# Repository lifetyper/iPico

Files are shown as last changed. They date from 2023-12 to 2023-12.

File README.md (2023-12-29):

# iPico
Open Hardware Secure Key Using Pico Fido Firmware

iPico PCB and Enclosure.

1.Using same gpio as raspi pico

2.Light guide using Φ2*2.54mm

3.Screw using M1*4mm

4.Keep USB footprint bottom side clean without too much solder

5.You might need to polish the outline of PCB if it's not done by the manufacture

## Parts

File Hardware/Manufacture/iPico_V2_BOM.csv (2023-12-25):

# | Reference | Qty | Value | Footprint | DNP
1 | C1, C2, C5, C6, C9, C10, C19 | 7 | C_0402_2.2uF_10V_X5R | Capacitor_SMD:C_0402_1005Metric
2 | C3 | 1 | C_0402_1uF_10V_X7R | Capacitor_SMD:C_0402_1005Metric
3 | C4, C8, C11, C12, C14, C15, C18 | 7 | C_0402_100nF_16V_X7R | Capacitor_SMD:C_0402_1005Metric
4 | C7, C17 | 2 | C_0402_22nF_50V_X7R | Capacitor_SMD:C_0402_1005Metric
5 | C13, C16 | 2 | C_0402_15pF_50V_C0G | Capacitor_SMD:C_0402_1005Metric
6 | D1, D2 | 2 | PESD0402-140 | Diode_SMD:D_0402_1005Metric
7 | D3 | 1 | NCD0603G1 | LED_SMD:LED_0603_1608Metric
8 | F1 | 1 | BSMD0603-020-16V | Fuse:Fuse_0603_1608Metric
9 | H1, H2, H3 | 3 | MountingHole_Pad | TinyMountingHole:MountingHole-M1
10 | J1 | 1 | GT-USB-8016A | GT-USB-8016A:GT-USB-8016A
11 | R1 | 1 | R_0402_5.1K_5% | Resistor_SMD:R_0402_1005Metric
12 | R2, R3 | 2 | R_0402_27_5% | Resistor_SMD:R_0402_1005Metric
13 | R4 | 1 | R_0402_200_5% | Resistor_SMD:R_0402_1005Metric
14 | R5, R6 | 2 | R_0402_1K_5% | Resistor_SMD:R_0402_1005Metric
15 | R7 | 1 | R_0402_470_5% | Resistor_SMD:R_0402_1005Metric
16 | SW1 | 1 | TS-1187A-C-H-B | SW_PUSH_1P1P_XKB_TS-1187A_W3D:SW_Push_1P1T_XKB_TS-1187A
17 | U1 | 1 | W25Q16JVUXIQ | USON8:USON8-2x3mm-EP0.2x1.6mm
18 | U2 | 1 | RT9013-33GB | Package_TO_SOT_SMD:SOT-23-5
19 | U4 | 1 | RP2040 | Package_DFN_QFN:QFN-56-1EP_7x7mm_P0.4mm_EP3.2x3.2mm
20 | Y1 | 1 | X322512MMB4SI | Crystal:Crystal_SMD_2520-4Pin_2.5x2.0mm

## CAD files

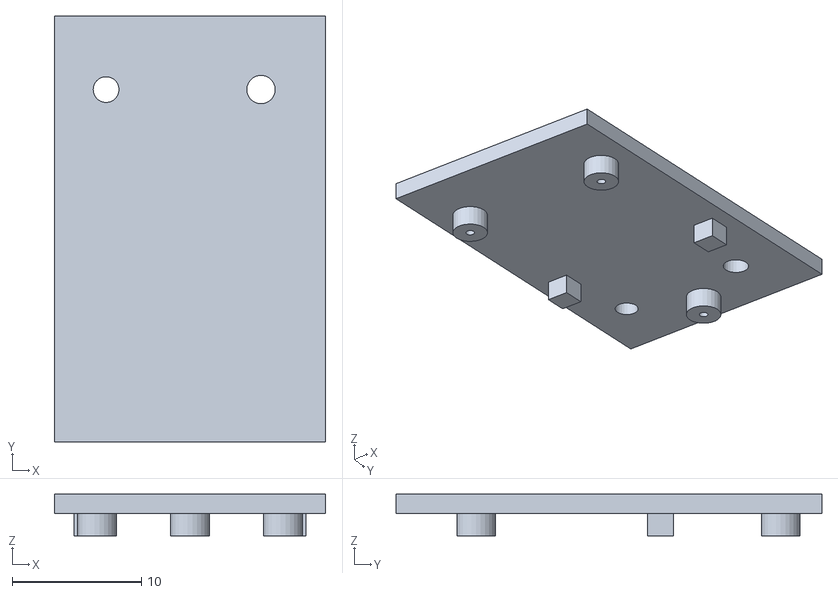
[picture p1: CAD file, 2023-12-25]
Mechanical/Enclosure/iPico_V2-Upper.stl
21.0 x 33.0 x 3.25

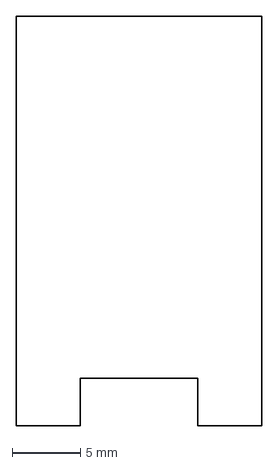
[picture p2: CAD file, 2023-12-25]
Mechanical/PCB_Outline/pcb_outline-Sketch.dxf
18.0 x 30.0 mm

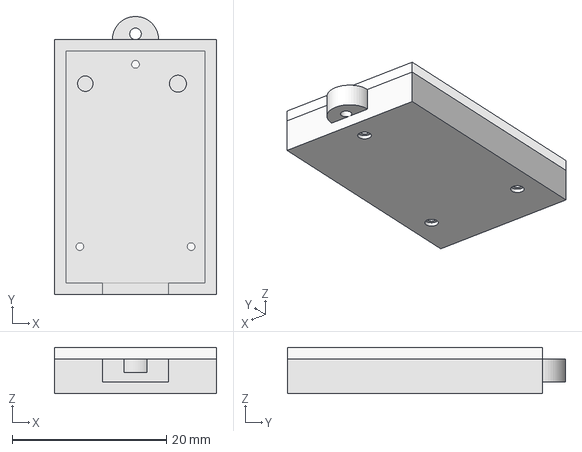
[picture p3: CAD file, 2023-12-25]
Mechanical/Enclosure/iPico_V2.FCStd
21.0 x 36.0 x 6.00 mm
Lower
Upper

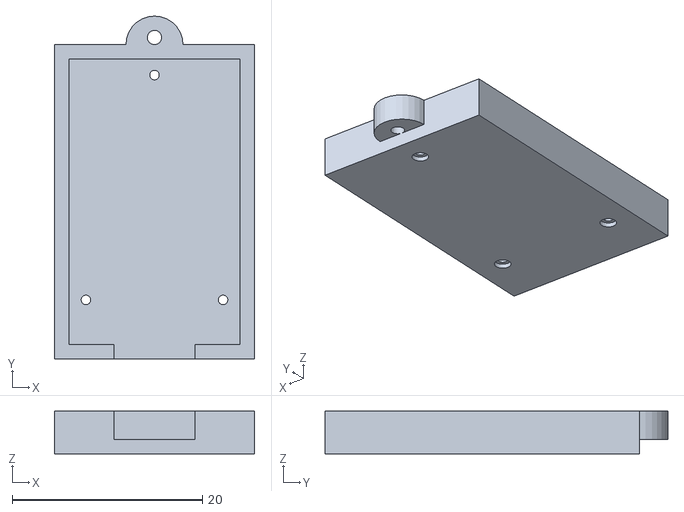
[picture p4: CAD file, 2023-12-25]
Mechanical/Enclosure/iPico_V2-Lower.stl
21.0 x 36.0 x 4.50

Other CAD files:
Mechanical/PCB_Outline/pcb_outline.FCStd

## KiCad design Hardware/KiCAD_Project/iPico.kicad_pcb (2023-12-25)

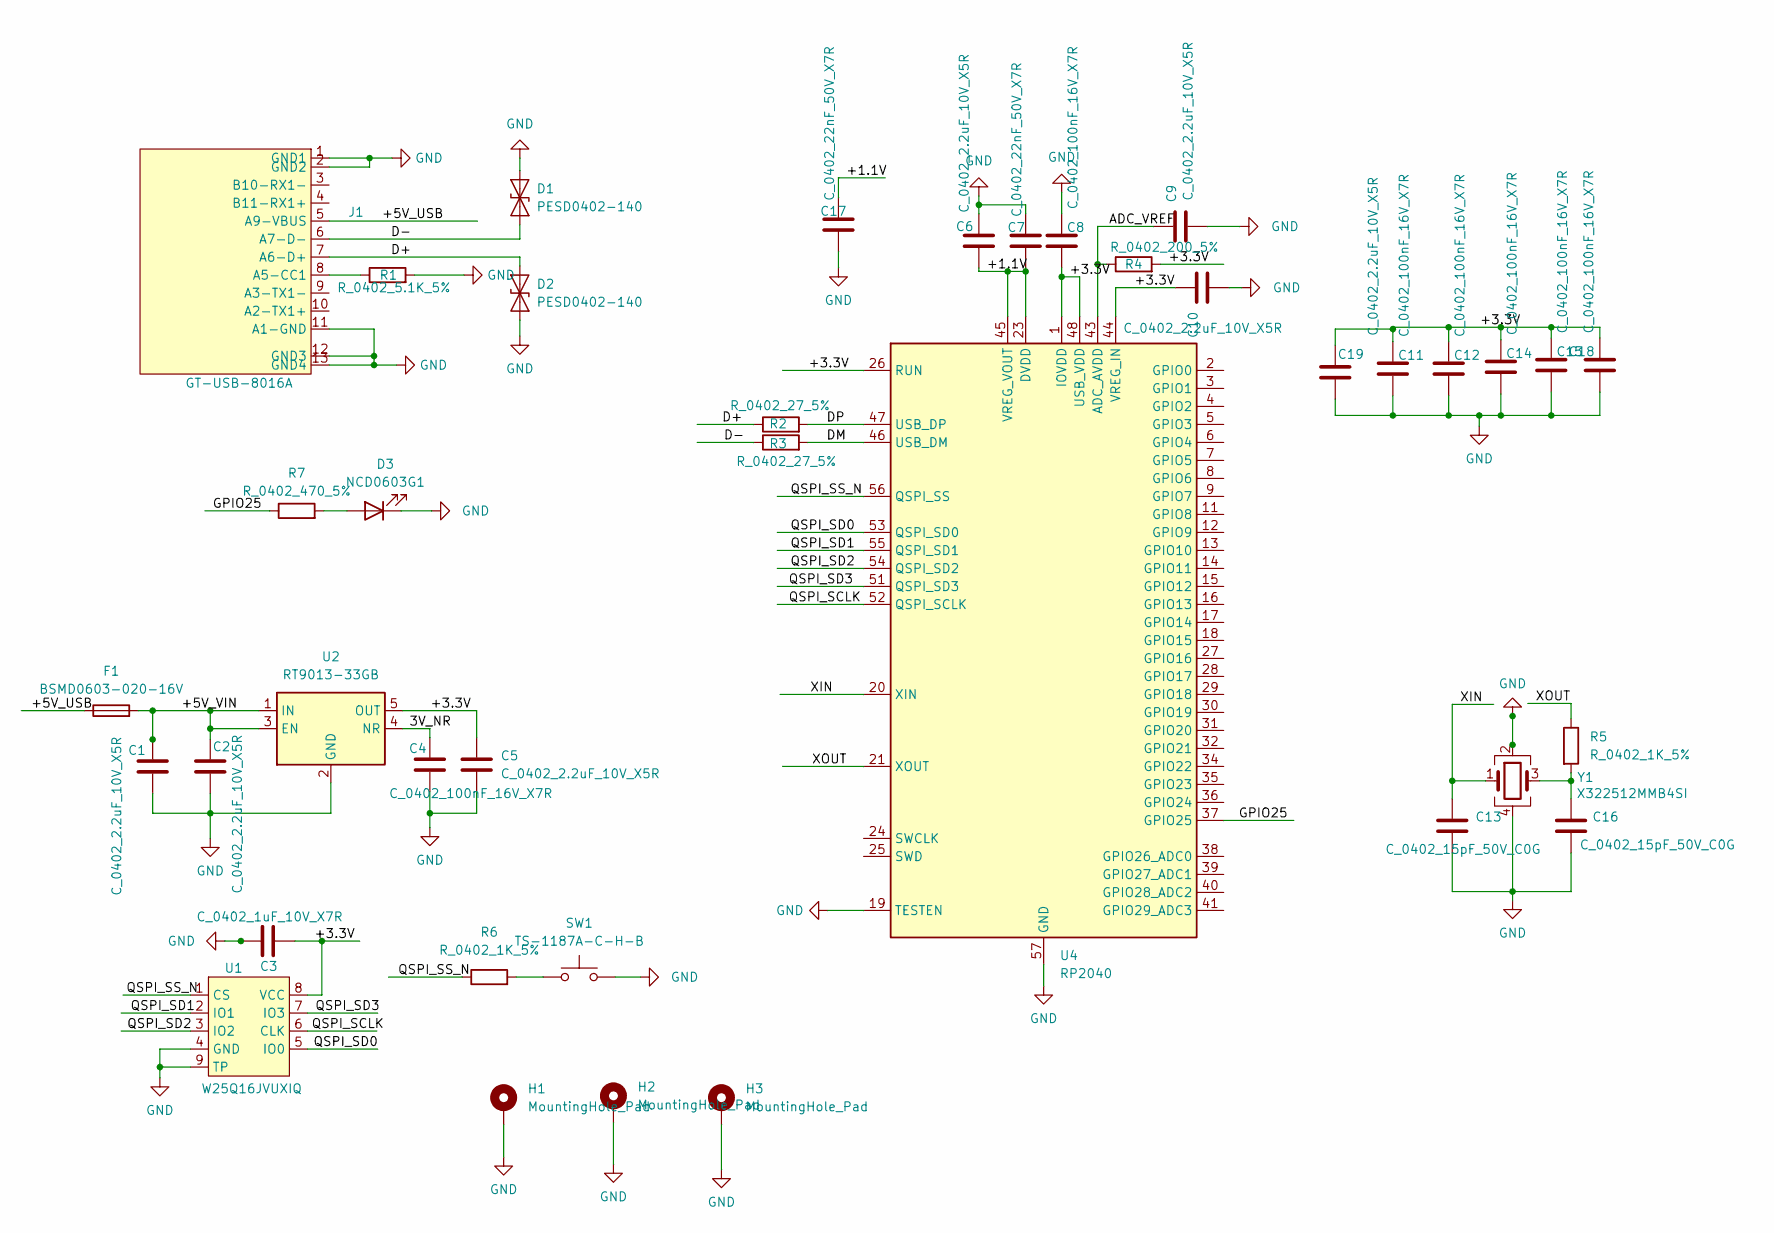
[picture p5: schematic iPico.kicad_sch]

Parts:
C1, C2, C5, C6, C9, C10, C19: C_0402_2.2uF_10V_X5R; C_0402_1005Metric
C3: C_0402_1uF_10V_X7R; C_0402_1005Metric
C4, C8, C11, C12, C14, C15, C18: C_0402_100nF_16V_X7R; C_0402_1005Metric
C7, C17: C_0402_22nF_50V_X7R; C_0402_1005Metric
C13, C16: C_0402_15pF_50V_C0G; C_0402_1005Metric
D1, D2: PESD0402-140; D_0402_1005Metric
D3: NCD0603G1; LED_0603_1608Metric
F1: BSMD0603-020-16V; Fuse_0603_1608Metric
H1, H2, H3: MountingHole_Pad; MountingHole-M1
J1: GT-USB-8016A
R1: R_0402_5.1K_5%; R_0402_1005Metric
R2, R3: R_0402_27_5%; R_0402_1005Metric
R4: R_0402_200_5%; R_0402_1005Metric
R5, R6: R_0402_1K_5%; R_0402_1005Metric
R7: R_0402_470_5%; R_0402_1005Metric
SW1: TS-1187A-C-H-B; SW_Push_1P1T_XKB_TS-1187A
U1: W25Q16JVUXIQ; USON8-2x3mm-EP0.2x1.6mm
U2: RT9013-33GB; SOT-23-5
U4: RP2040; QFN-56-1EP_7x7mm_P0.4mm_EP3.2x3.2mm
Y1: X322512MMB4SI; Crystal_SMD_2520-4Pin_2.5x2.0mm

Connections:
/3V_NR: C4.1, U2.4 (NR)
/+1.1V: C6.2, C7.2, C17.1, U4.23 (DVDD), U4.45 (VREG_VOUT), U4.50 (DVDD)
/+3.3V: C3.2, C5.1, C8.2, C10.1, C11.1, C12.1, C14.1, C15.1, C18.1, C19.2, R4.2, U1.8 (VCC), U2.5 (OUT), U4.1 (IOVDD), U4.10 (IOVDD), U4.22 (IOVDD), U4.26 (RUN), U4.33 (IOVDD), U4.42 (IOVDD), U4.44 (VREG_IN), U4.48 (USB_VDD), U4.49 (IOVDD)
/+5V_USB: F1.1, J1.5 (A9-VBUS)
/+5V_VIN: C1.1, C2.1, F1.2, U2.1 (IN), U2.3 (EN)
/ADC_VREF: C9.1, R4.1, U4.43 (ADC_AVDD)
/D+: D2.2 (A2), J1.7 (A6-D+), R2.1
/D-: D1.1 (A1), J1.6 (A7-D-), R3.1
/DM: R3.2, U4.46 (USB_DM)
/DP: R2.2, U4.47 (USB_DP)
/GPIO25: R7.1, U4.37 (GPIO25)
/QSPI_SCLK: U1.6 (CLK), U4.52 (QSPI_SCLK)
/QSPI_SD0: U1.5 (IO0), U4.53 (QSPI_SD0)
/QSPI_SD1: U1.2 (IO1), U4.55 (QSPI_SD1)
/QSPI_SD2: U1.3 (IO2), U4.54 (QSPI_SD2)
/QSPI_SD3: U1.7 (IO3), U4.51 (QSPI_SD3)
/QSPI_SS_N: R6.1, U1.1 (CS), U4.56 (QSPI_SS)
/XIN: C13.1, U4.20 (XIN), Y1.1
/XOUT: R5.1, U4.21 (XOUT)
GND: C1.2, C2.2, C3.1, C4.2, C5.2, C6.1, C7.1, C8.1, C9.2, C10.2, C11.2, C12.2, C13.2, C14.2, C15.2, C16.2, C17.2, C18.2, C19.1, D1.2 (A2), D2.1 (A1), D3.1 (K), H1.1, H2.1, H3.1, J1.1 (GND1), J1.2 (GND2), J1.11 (A1-GND), J1.12 (GND3), J1.13 (GND4), R1.2, SW1.2, U1.4 (GND), U1.9 (TP), U2.2 (GND), U4.19 (TESTEN), U4.57 (GND), Y1.2, Y1.4
unnamed: C16.1, R5.2, Y1.3
unnamed: D3.2 (A), R7.2
unnamed: J1.8 (A5-CC1), R1.1
unnamed: R6.2, SW1.1

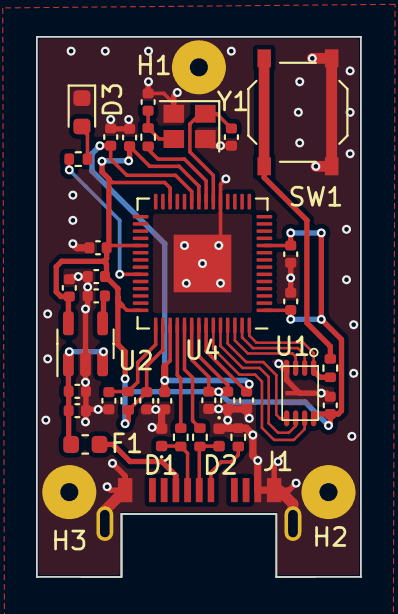
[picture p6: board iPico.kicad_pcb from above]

Board: 2 copper layers, 18.0 x 30.0 mm, 39 parts (0 on the bottom side), 24 nets.
